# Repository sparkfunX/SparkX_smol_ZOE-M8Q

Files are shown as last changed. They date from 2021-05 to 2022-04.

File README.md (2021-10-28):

# SparkX smôl ZOE-M8Q

SparkX smôl ZOE-M8Q (SPX-18623) (https://www.sparkfun.com/products/18623)

[*SparkX smôl ZOE-M8Q (SPX-18623)*](https://www.sparkfun.com/products/18623)

The u-blox ZOE-M8Q in smôl format.

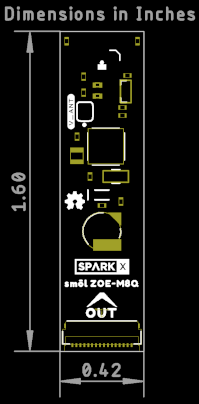
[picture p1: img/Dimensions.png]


## Repository Contents

- **/Documentation** - Datasheets etc.
- **/Hardware** - Eagle design files
- **LICENSE.md** contains the licence information

## Product Versions

- [SPX-18623](https://www.sparkfun.com/products/18623) - Original SparkX Release.

## License Information

This product is _**open source**_!

Please review the LICENSE.md file for license information.

If you have any questions or concerns on licensing, please contact technical support on our [SparkFun forums](https://forum.sparkfun.com/viewforum.php?f=123).

Distributed as-is; no warranty is given.

- Your friends at SparkFun.

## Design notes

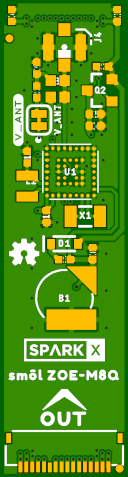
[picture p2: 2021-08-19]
img/Top.png

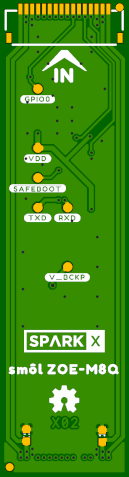
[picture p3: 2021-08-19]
img/Bottom.png

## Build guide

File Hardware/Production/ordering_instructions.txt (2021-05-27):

JLCPCB JLC7628 4-Layer 0.8mm Impedance Control
panel size, 193x137mm
PCB thickness, 0.8mm
number of layers, 4
soldermask color, Black
silkscreen color, White
oz copper, 1oz
finish, ENIG
stencils, top+bottom
pcs per panel, 48
min trace width, 0.1270mm / 0.0050in
min drill size, 0.2000mm / 0.0079in
filename to layer stackup 1/2/3/4: GTL, GL2, GL3, GBL

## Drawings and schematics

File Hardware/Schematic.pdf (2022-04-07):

# VDD GND

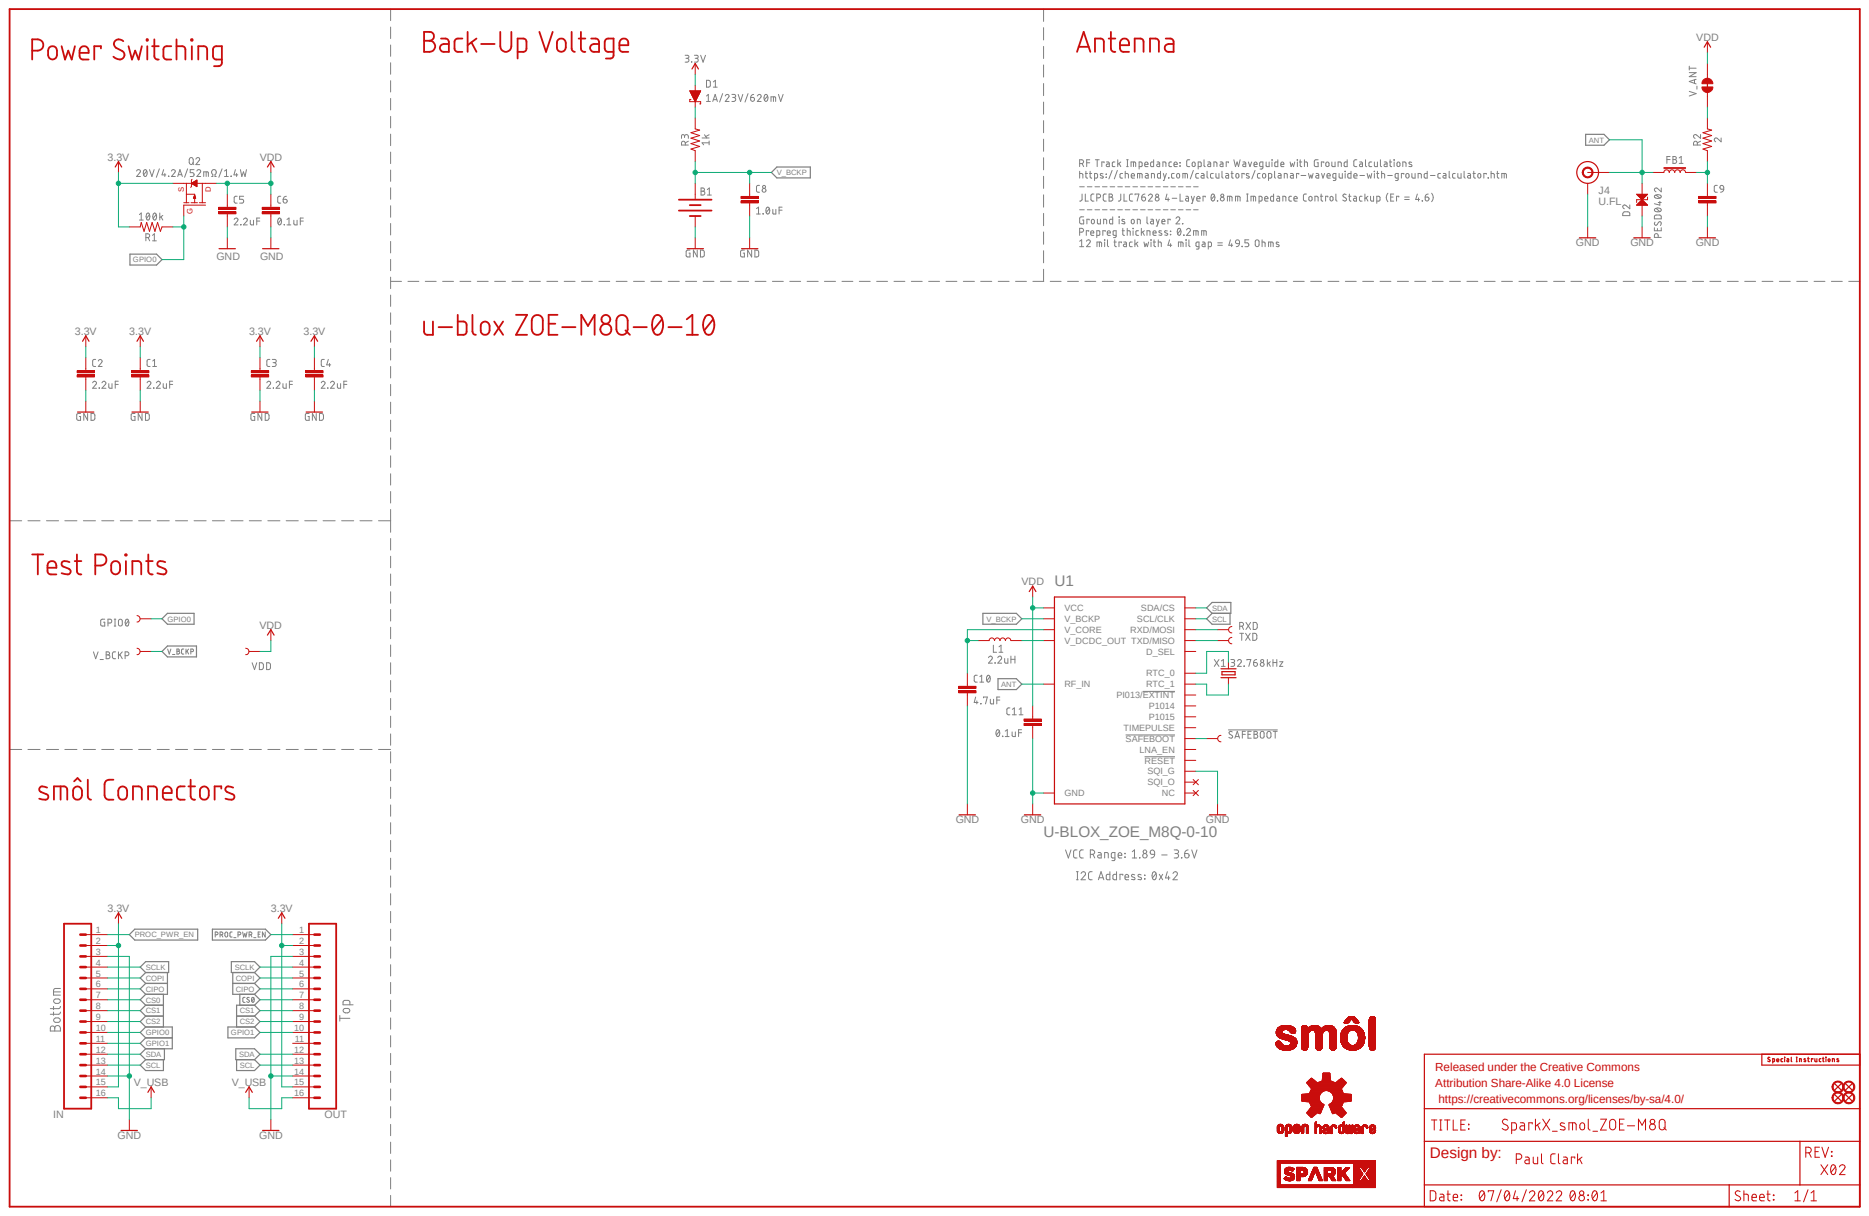
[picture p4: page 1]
VDD GND; GND; VDD; V_USB; U-BLOX_ZOE_M8Q-0-10; GND GND; 1 2 3 4 5 6 7 8 9 10 11 12 13 14 15 16 OUT; VCC GND; RTC_0 RTC_1 TIMEPULSE; SAFEBOOT LNA_EN; P1015 P1014 PI013/EXTINT RESET SQI_G; V_CORE V_DCDC_OUT; V_BCKP; SQI_O NC; SCLK; SCLK COPI; COPI CIPO; CIPO; GPIO0; GPIO0 CS1; CS2 GPIO1; GPIO1 SDA; SDA; SCL; SCL ANT; ANT; PROC_PWR_EN; Design by:

SDA/CS
SCL/CLK D_SEL RXD/MOSI TXD/MISO

Released under the Creative Commons
Attribution Share-Alike 4.0 License
https://creativecommons.org/licenses/by-sa/4.0/

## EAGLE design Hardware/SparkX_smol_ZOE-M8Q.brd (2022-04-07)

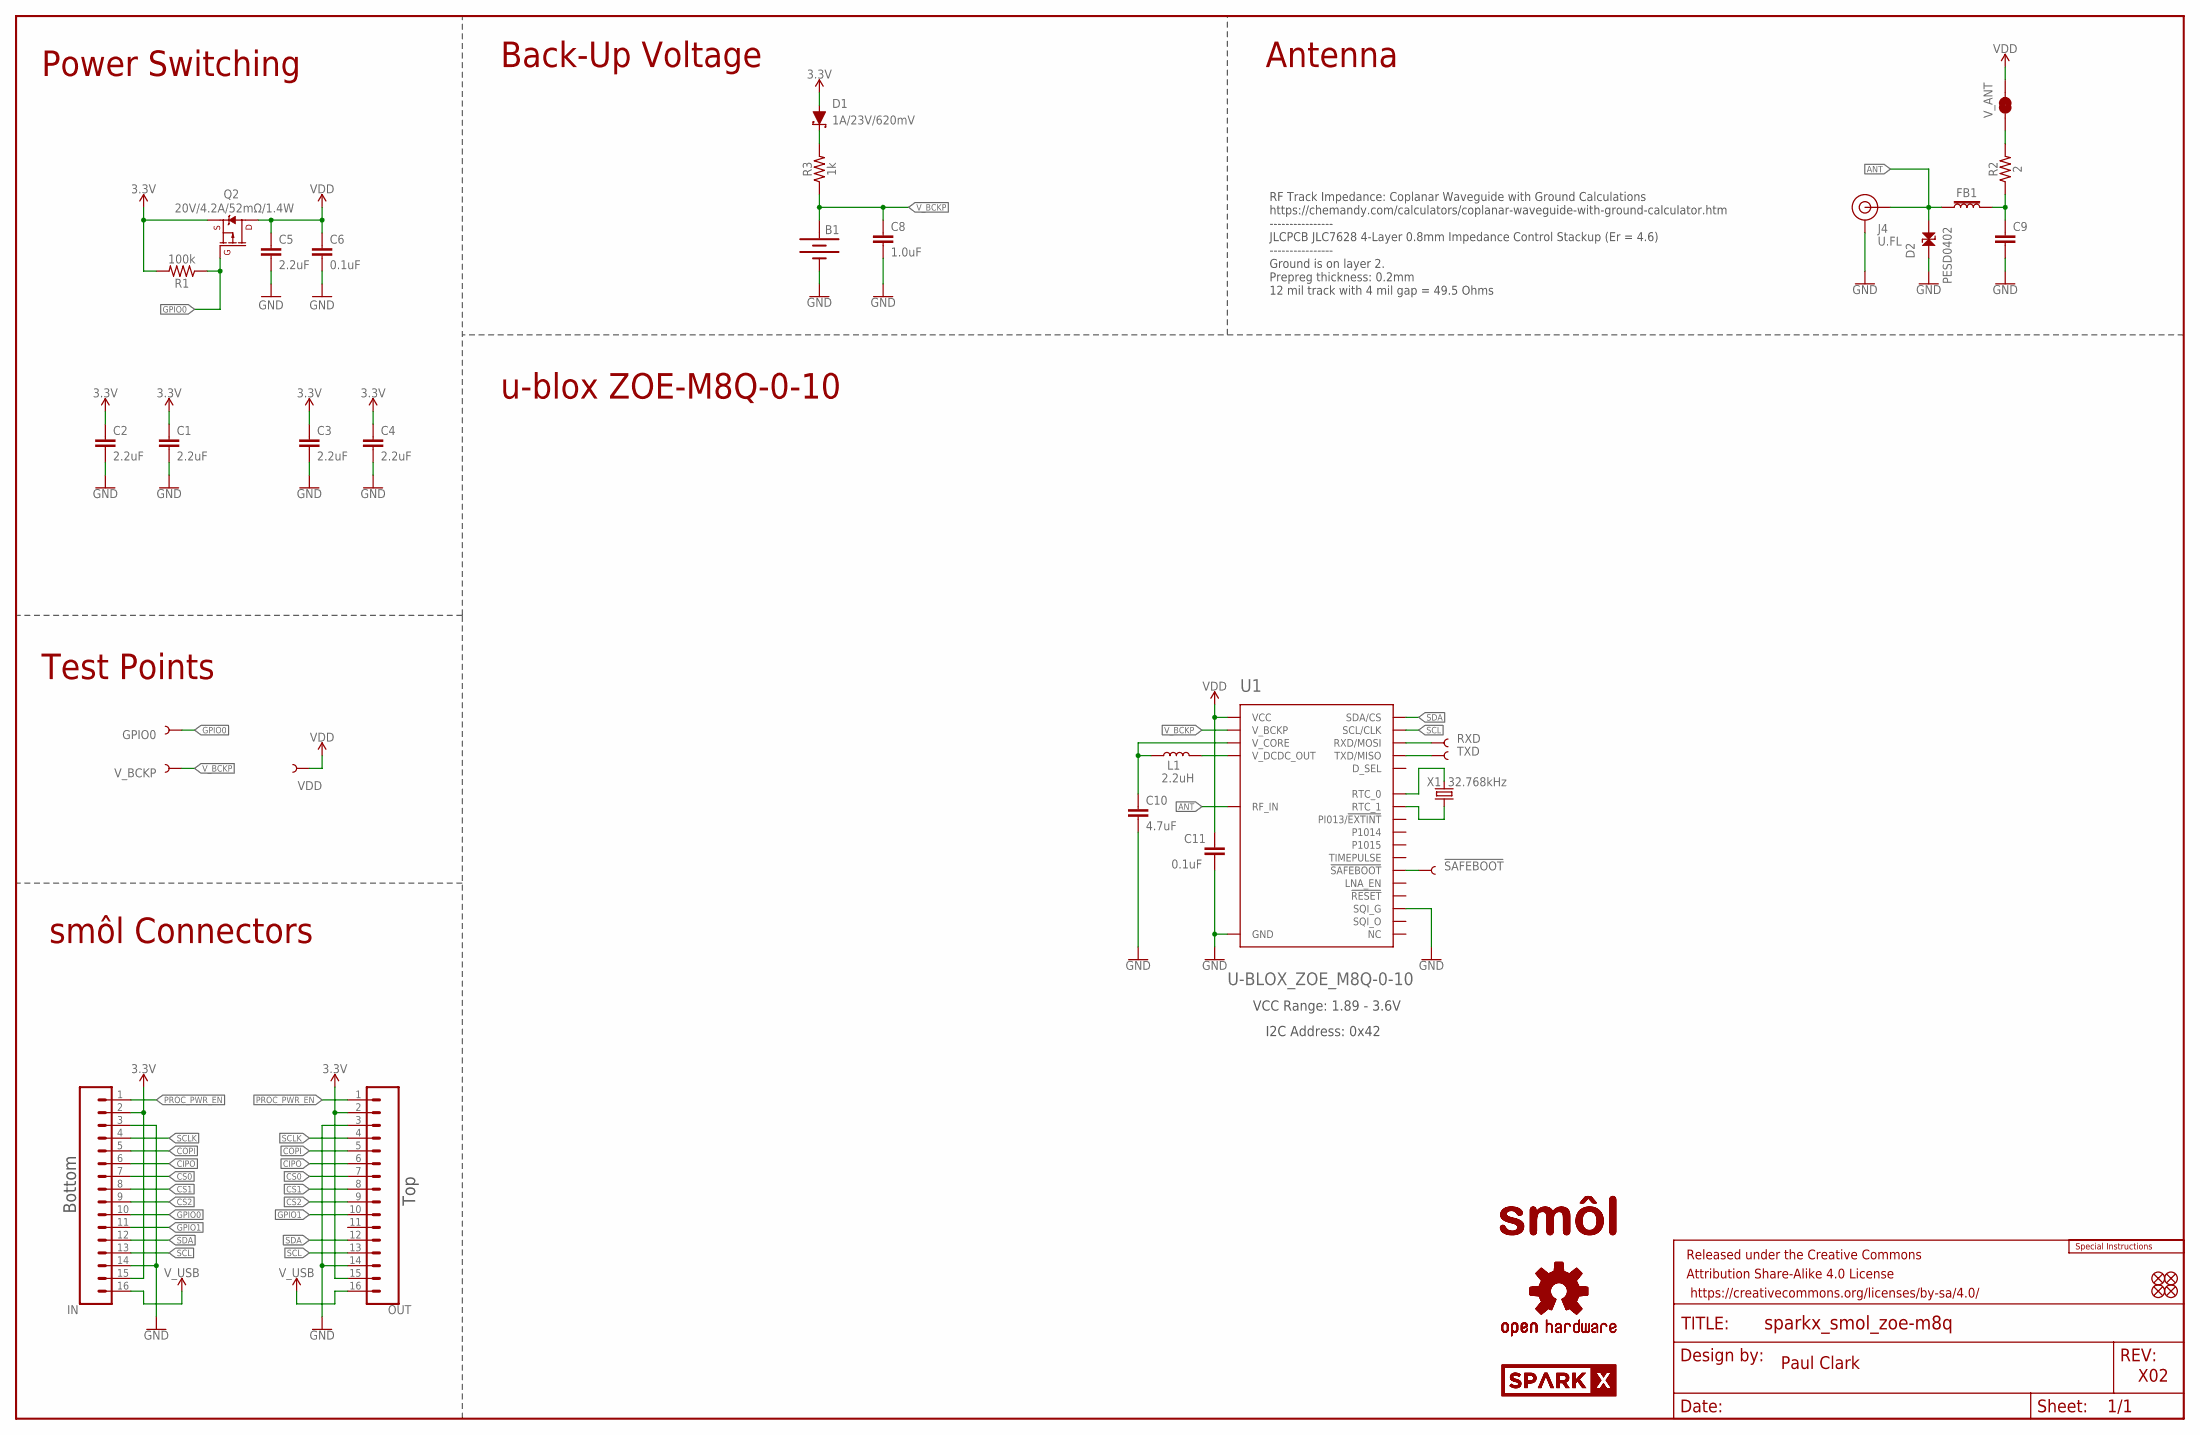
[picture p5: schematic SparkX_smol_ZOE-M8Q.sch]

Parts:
!SAFEBOOT!: TEST-POINT3; PAD.03X.03
B1: 6.8MM_COIN_CELL; ML414H_IV01E
C1, C2, C3, C4, C5: 2.2uF; 0402-TIGHT
C6, C11: 0.1uF; 0402-TIGHT
C8: 1.0uF; 0402-TIGHT
C9: 47PF-0402_TIGHT-25V-5%-X7R; 0402-TIGHT
C10: 4.7uF; 0402-TIGHT
D1: 1A/23V/620mV; SOD-323
D2: PESD0402; 0402
FB1: FERRITE_BEAD-120_OHM-0402; 0402
FD1, FD2, FD3, FD4: FIDUCIALUFIDUCIAL; FIDUCIAL-MICRO
FRAME1: FRAME-LEDGER; CREATIVE_COMMONS
GPIO0: TEST-POINT3; PAD.03X.03
IN: CONN_16FPC_16_0.5MM; FPC_16_0.5MM
J4: U.FL
L1: 2.2uH; 0806
LOGO1: SPECIAL_INSTRUCTIONS-ORDERING; ORDERING_INSTRUCTIONS
LOGO2, LOGO3: OSHW-LOGOMINI; OSHW-LOGO-MINI
OUT: CONN_16FPC_16_0.5MM; FPC_16_0.5MM
Q2: 20V/4.2A/52mΩ/1.4W; SOT23-3
R1: 100k; 0402-TIGHT
R2: 2; 0402-TIGHT
R3: 1k; 0402-TIGHT
RXD: TEST-POINT3; PAD.03X.03
TXD: TEST-POINT3; PAD.03X.03
U1: U-BLOX_ZOE_M8Q-0-10; UBLOX_ZOE_M8-0-10
U$1, U$4: SPARKX-LOGO3; SPARKX-SMALL
U$3, U$13: SMOL_LOGOSMALL; SMOL_SMALL
VDD: TEST-POINT3; PAD.03X.03
V_ANT: JUMPER-SMT_2_NC_TRACE_SILK; SMT-JUMPER_2_NC_TRACE_SILK
V_BCKP: TEST-POINT3; PAD.03X.03
X1: 32.768kHz; CRYSTAL-SMD-3.2X1.5MM

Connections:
3.3V: C1.1, C2.1, C3.1, C4.1, D1.A, IN.2, IN.15, OUT.2, OUT.15, Q2.2 (S), R1.2
!SAFEBOOT!: !SAFEBOOT!.1, U1.34 (!SAFEBOOT)
ANT: D2.2, FB1.1, J4.FEED (SIGNAL), U1.4 (RF_IN)
CIPO: IN.6, OUT.6
COPI: IN.5, OUT.5
CS0: IN.7, OUT.7
CS1: IN.8, OUT.8
CS2: IN.9, OUT.9
GND: B1.-, C1.2, C2.2, C3.2, C4.2, C5.2, C6.2, C8.2, C9.2, C10.2, C11.2, D2.1, IN.3, IN.14, J4.1 (GND), J4.2 (GND), OUT.3, OUT.14, U1.1 (GND), U1.3 (GND), U1.5 (GND), U1.7 (GND), U1.8 (GND), U1.9 (GND), U1.10 (GND), U1.11 (GND), U1.12 (GND), U1.17 (GND), U1.23 (GND), U1.29 (SQI_G), U1.31 (SQI_G), U1.37 (GND), U1.38 (GND), U1.39 (GND), U1.40 (GND), U1.41 (GND), U1.44 (GND), U1.46 (SQI_G), U1.47 (SQI_G), U1.49 (GND)
GPIO0: GPIO0.1, IN.10, Q2.1 (G), R1.1
GPIO1: IN.11, OUT.10
unnamed: R2.2, V_ANT.1
unnamed: D1.C, R3.2
unnamed: L1.2, U1.26 (V_DCDC_OUT)
unnamed: C10.1, L1.1, U1.27 (V_CORE)
unnamed: U1.18 (RTC_0), X1.P$2 (2)
unnamed: U1.19 (RTC_1), X1.P$1 (1)
unnamed: C9.1, FB1.2, R2.1
PROC_PWR_EN: IN.1, OUT.1
RXD: RXD.1, U1.22 (RXD/MOSI)
SCL: IN.13, OUT.13, U1.32 (SCL/CLK)
SCLK: IN.4, OUT.4
SDA: IN.12, OUT.12, U1.2 (SDA/CS)
TXD: TXD.1, U1.21 (TXD/MISO)
VDD: C5.1, C6.1, C11.1, Q2.3 (D), U1.24 (VCC), U1.25 (VCC), VDD.1, V_ANT.2
V_BCKP: B1.+, C8.1, R3.1, U1.16 (V_BCKP), V_BCKP.1
V_USB: IN.16, OUT.16

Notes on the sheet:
Paul Clark
X02
Test Points
RF Track Impedance: Coplanar Waveguide with Ground Calculations https://chemandy.com/calculators/coplanar-waveguide-with-ground-calculator.htm ---------------- JLCPCB JLC7628 4-Layer 0.8mm Impedance Control Stackup (Er = 4.6) ---------------- Ground is on layer 2. Prepreg thickness: 0.2mm 12 mil tr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
Power Switching
smôl Connectors
Bottom
Top
u-blox ZOE-M8Q-0-10
Back-Up Voltage
Antenna
VCC Range: 1.89 - 3.6V
I2C Address: 0x42

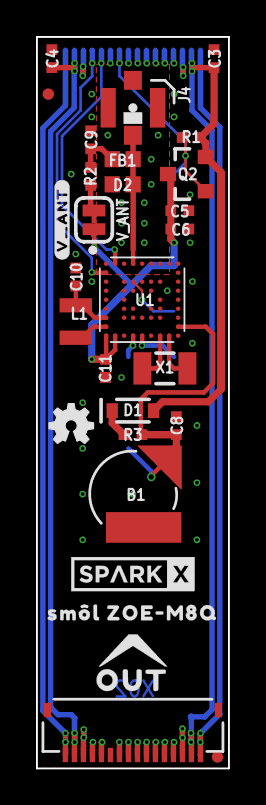
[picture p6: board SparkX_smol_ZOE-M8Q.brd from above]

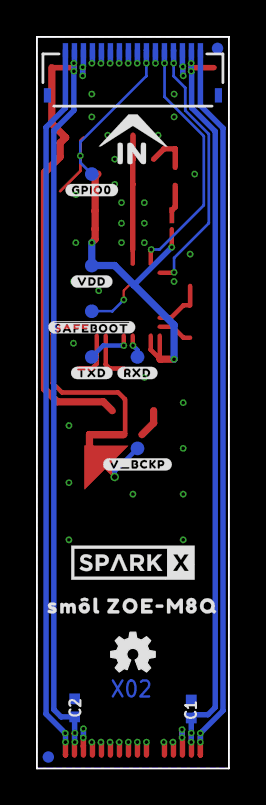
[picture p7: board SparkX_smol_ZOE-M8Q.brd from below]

Board: 4 copper layers, 10.7 x 40.6 mm, 54 parts (22 on the bottom side), 27 nets.

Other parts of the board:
U$2, U$12: SM�L_ZOE#M8Q0
U$5: #V_ANT#0
U$6: #VDD#0
U$7: ##SAFEBOOT##0
U$8: #TXD#0
U$9: #RXD#0
U$10: #GPIO0#0
U$11: #V_BCKP#0
U$14: OUT0
U$15: IN0

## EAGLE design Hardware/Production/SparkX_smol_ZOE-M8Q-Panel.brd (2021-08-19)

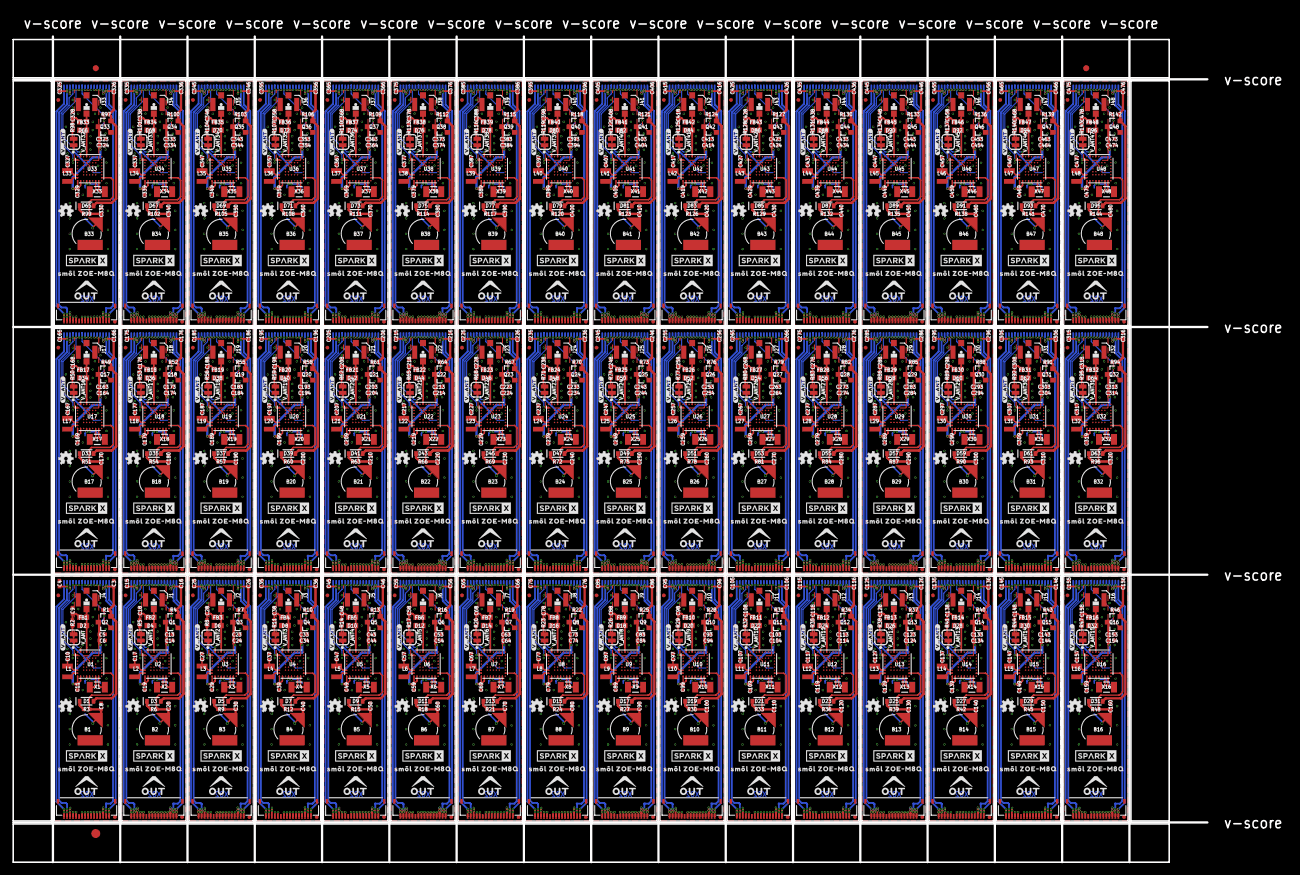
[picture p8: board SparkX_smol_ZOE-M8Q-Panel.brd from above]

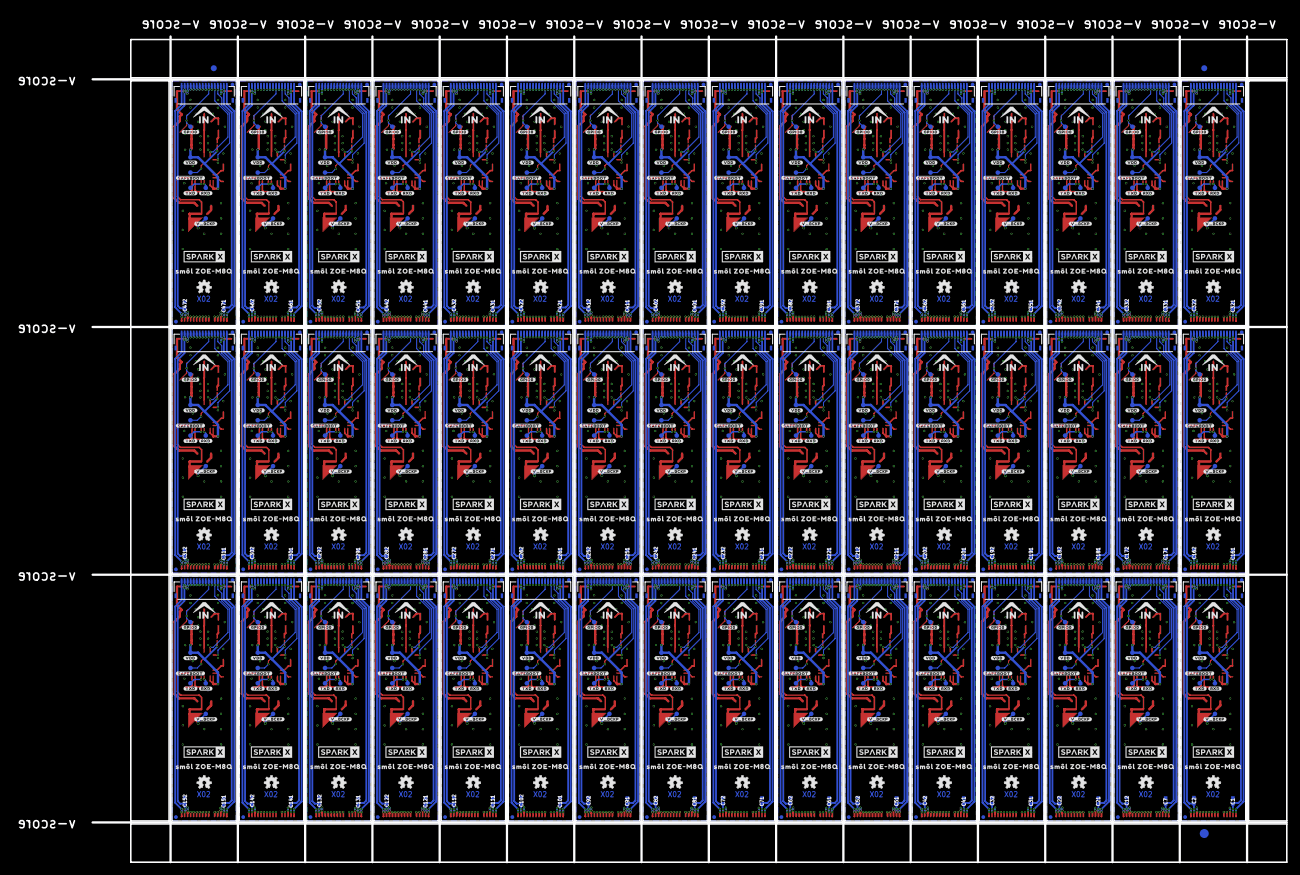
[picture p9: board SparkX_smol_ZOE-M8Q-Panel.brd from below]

Board: 4 copper layers, 198.4 x 137.2 mm, 2502 parts (1059 on the bottom side), 1296 nets.

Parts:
!SAFEBOOT!, !SAFEBOOT!1, !SAFEBOOT!2, !SAFEBOOT!3, !SAFEBOOT!4, !SAFEBOOT!5, !SAFEBOOT!6, !SAFEBOOT!7, !SAFEBOOT!8, !SAFEBOOT!9, !SAFEBOOT!10, !SAFEBOOT!11, !SAFEBOOT!12, !SAFEBOOT!13, !SAFEBOOT!14, !SAFEBOOT!15, !SAFEBOOT!16, !SAFEBOOT!17, !SAFEBOOT!18, !SAFEBOOT!19, !SAFEBOOT!20, !SAFEBOOT!21, !SAFEBOOT!22, !SAFEBOOT!23, !SAFEBOOT!24, !SAFEBOOT!25, !SAFEBOOT!26, !SAFEBOOT!27, !SAFEBOOT!28, !SAFEBOOT!29, !SAFEBOOT!30, !SAFEBOOT!31, !SAFEBOOT!32, !SAFEBOOT!33, !SAFEBOOT!34, !SAFEBOOT!35, !SAFEBOOT!36, !SAFEBOOT!37, !SAFEBOOT!38, !SAFEBOOT!39, !SAFEBOOT!40, !SAFEBOOT!41, !SAFEBOOT!42, !SAFEBOOT!43, !SAFEBOOT!44, !SAFEBOOT!45, !SAFEBOOT!46, !SAFEBOOT!47: TEST-POINT3; PAD.03X.03
B1, B2, B3, B4, B5, B6, B7, B8, B9, B10, B11, B12, B13, B14, B15, B16, B17, B18, B19, B20, B21, B22, B23, B24, B25, B26, B27, B28, B29, B30, B31, B32, B33, B34, B35, B36, B37, B38, B39, B40, B41, B42, B43, B44, B45, B46, B47, B48: 6.8MM_COIN_CELL; ML414H_IV01E
C1, C2, C3, C4, C5, C7, C12, C13, C15, C16, C21, C22, C23, C25, C26, C31, C32, C33, C35, C36, C41, C42, C43, C45, C46, C51, C52, C53, C55, C56, C61, C62, C63, C65, C66, C71, C72, C73, C75, C76, C81, C82, C83, C85, C86, C91, C92, C93, C95, C96, C101, C102, C103, C105, C106, C111, C112, C113, C115, C116, C121, C122, C123, C125, C126, C131, C132, C133, C135, C136, C141, C142, C143, C145, C146, C151, C152, C153, C155, C156, C161, C162, C163, C165, C166, C171, C172, C173, C175, C176, C181, C182, C183, C185, C186, C191, C192, C193, C195, C196, C201, C202, C203, C205, C206, C211, C212, C213, C215, C216, C221, C222, C223, C225, C226, C231, C232, C233, C235, C236, C241, C242, C243, C245, C246, C251, C252, C253, C255, C256, C261, C262, C263, C265, C266, C271, C272, C273, C275, C276, C281, C282, C283, C285, C286, C291, C292, C293, C295, C296, C301, C302, C303, C305, C306, C311, C312, C313, C315, C316, C321, C322, C323, C325, C326, C331, C332, C333, C335, C336, C341, C342, C343, C345, C346, C351, C352, C353, C355, C356, C361, C362, C363, C365, C366, C371, C372, C373, C375, C376, C381, C382, C383, C385, C386, C391, C392, C393, C395, C396, C401, C402, C403, C405, C406, C411, C412, C413, C415, C416, C421, C422, C423, C425, C426, C431, C432, C433, C435, C436, C441, C442, C443, C445, C446, C451, C452, C453, C455, C456, C461, C462, C463, C465, C466, C471, C472, C473, C475, C476: 2.2uF; 0402-TIGHT
C6, C11, C14, C19, C24, C29, C34, C39, C44, C49, C54, C59, C64, C69, C74, C79, C84, C89, C94, C99, C104, C109, C114, C119, C124, C129, C134, C139, C144, C149, C154, C159, C164, C169, C174, C179, C184, C189, C194, C199, C204, C209, C214, C219, C224, C229, C234, C239, C244, C249, C254, C259, C264, C269, C274, C279, C284, C289, C294, C299, C304, C309, C314, C319, C324, C329, C334, C339, C344, C349, C354, C359, C364, C369, C374, C379, C384, C389, C394, C399, C404, C409, C414, C419, C424, C429, C434, C439, C444, C449, C454, C459, C464, C469, C474, C479: 0.1uF; 0402-TIGHT
C8, C20, C30, C40, C50, C60, C70, C80, C90, C100, C110, C120, C130, C140, C150, C160, C170, C180, C190, C200, C210, C220, C230, C240, C250, C260, C270, C280, C290, C300, C310, C320, C330, C340, C350, C360, C370, C380, C390, C400, C410, C420, C430, C440, C450, C460, C470, C480: 1.0uF; 0402-TIGHT
C9, C18, C28, C38, C48, C58, C68, C78, C88, C98, C108, C118, C128, C138, C148, C158, C168, C178, C188, C198, C208, C218, C228, C238, C248, C258, C268, C278, C288, C298, C308, C318, C328, C338, C348, C358, C368, C378, C388, C398, C408, C418, C428, C438, C448, C458, C468, C478: 47PF-0402_TIGHT-25V-5%-X7R; 0402-TIGHT
C10, C17, C27, C37, C47, C57, C67, C77, C87, C97, C107, C117, C127, C137, C147, C157, C167, C177, C187, C197, C207, C217, C227, C237, C247, C257, C267, C277, C287, C297, C307, C317, C327, C337, C347, C357, C367, C377, C387, C397, C407, C417, C427, C437, C447, C457, C467, C477: 4.7uF; 0402-TIGHT
D1, D3, D5, D7, D9, D11, D13, D15, D17, D19, D21, D23, D25, D27, D29, D31, D33, D35, D37, D39, D41, D43, D45, D47, D49, D51, D53, D55, D57, D59, D61, D63, D65, D67, D69, D71, D73, D75, D77, D79, D81, D83, D85, D87, D89, D91, D93, D95: 1A/23V/620mV; SOD-323
D2, D4, D6, D8, D10, D12, D14, D16, D18, D20, D22, D24, D26, D28, D30, D32, D34, D36, D38, D40, D42, D44, D46, D48, D50, D52, D54, D56, D58, D60, D62, D64, D66, D68, D70, D72, D74, D76, D78, D80, D82, D84, D86, D88, D90, D92, D94, D96: PESD0402; 0402
E$1, E$2, E$3, E$4: FIDUCIAL-1X2
E$5, E$6: FIDUCIAL-1.5X3
FB1, FB2, FB3, FB4, FB5, FB6, FB7, FB8, FB9, FB10, FB11, FB12, FB13, FB14, FB15, FB16, FB17, FB18, FB19, FB20, FB21, FB22, FB23, FB24, FB25, FB26, FB27, FB28, FB29, FB30, FB31, FB32, FB33, FB34, FB35, FB36, FB37, FB38, FB39, FB40, FB41, FB42, FB43, FB44, FB45, FB46, FB47, FB48: FERRITE_BEAD-120_OHM-0402; 0402
FD1, FD2, FD3, FD4, FD5, FD6, FD7, FD8, FD9, FD10, FD11, FD12, FD13, FD14, FD15, FD16, FD17, FD18, FD19, FD20, FD21, FD22, FD23, FD24, FD25, FD26, FD27, FD28, FD29, FD30, FD31, FD32, FD33, FD34, FD35, FD36, FD37, FD38, FD39, FD40, FD41, FD42, FD43, FD44, FD45, FD46, FD47, FD48, FD49, FD50, FD51, FD52, FD53, FD54, FD55, FD56, FD57, FD58, FD59, FD60, FD61, FD62, FD63, FD64, FD65, FD66, FD67, FD68, FD69, FD70, FD71, FD72, FD73, FD74, FD75, FD76, FD77, FD78, FD79, FD80, FD81, FD82, FD83, FD84, FD85, FD86, FD87, FD88, FD89, FD90, FD91, FD92, FD93, FD94, FD95, FD96, FD97, FD98, FD99, FD100, FD101, FD102, FD103, FD104, FD105, FD106, FD107, FD108, FD109, FD110, FD111, FD112, FD113, FD114, FD115, FD116, FD117, FD118, FD119, FD120, FD121, FD122, FD123, FD124, FD125, FD126, FD127, FD128, FD129, FD130, FD131, FD132, FD133, FD134, FD135, FD136, FD137, FD138, FD139, FD140, FD141, FD142, FD143, FD144, FD145, FD146, FD147, FD148, FD149, FD150, FD151, FD152, FD153, FD154, FD155, FD156, FD157, FD158, FD159, FD160, FD161, FD162, FD163, FD164, FD165, FD166, FD167, FD168, FD169, FD170, FD171, FD172, FD173, FD174, FD175, FD176, FD177, FD178, FD179, FD180, FD181, FD182, FD183, FD184, FD185, FD186, FD187, FD188, FD189, FD190, FD191, FD192: FIDUCIALUFIDUCIAL; FIDUCIAL-MICRO
GPIO0, GPIO1, GPIO2, GPIO3, GPIO4, GPIO5, GPIO6, GPIO7, GPIO8, GPIO9, GPIO10, GPIO11, GPIO12, GPIO13, GPIO14, GPIO15, GPIO16, GPIO17, GPIO18, GPIO19, GPIO20, GPIO21, GPIO22, GPIO23, GPIO24, GPIO25, GPIO26, GPIO27, GPIO28, GPIO29, GPIO30, GPIO31, GPIO32, GPIO33, GPIO34, GPIO35, GPIO36, GPIO37, GPIO38, GPIO39, GPIO40, GPIO41, GPIO42, GPIO43, GPIO44, GPIO45, GPIO46, GPIO47: TEST-POINT3; PAD.03X.03
IN, IN1, IN2, IN3, IN4, IN5, IN6, IN7, IN8, IN9, IN10, IN11, IN12, IN13, IN14, IN15, IN16, IN17, IN18, IN19, IN20, IN21, IN22, IN23, IN24, IN25, IN26, IN27, IN28, IN29, IN30, IN31, IN32, IN33, IN34, IN35, IN36, IN37, IN38, IN39, IN40, IN41, IN42, IN43, IN44, IN45, IN46, IN47: FPC_16_0.5MM
J1, J2, J3, J4, J5, J6, J7, J8, J9, J10, J11, J12, J13, J14, J15, J16, J17, J18, J19, J20, J21, J22, J23, J24, J25, J26, J27, J28, J29, J30, J31, J32, J33, J34, J35, J36, J37, J38, J39, J40, J41, J42, J43, J44, J45, J46, J47, J48: U.FL
L1, L2, L3, L4, L5, L6, L7, L8, L9, L10, L11, L12, L13, L14, L15, L16, L17, L18, L19, L20, L21, L22, L23, L24, L25, L26, L27, L28, L29, L30, L31, L32, L33, L34, L35, L36, L37, L38, L39, L40, L41, L42, L43, L44, L45, L46, L47, L48: 2.2uH; 0806
LOGO1, LOGO2, LOGO3, LOGO4, LOGO5, LOGO6, LOGO7, LOGO8, LOGO9, LOGO10, LOGO11, LOGO12, LOGO13, LOGO14, LOGO15, LOGO16, LOGO17, LOGO18, LOGO19, LOGO20, LOGO21, LOGO22, LOGO23, LOGO24, LOGO25, LOGO26, LOGO27, LOGO28, LOGO29, LOGO30, LOGO31, LOGO32, LOGO33, LOGO34, LOGO35, LOGO36, LOGO37, LOGO38, LOGO39, LOGO40, LOGO41, LOGO42, LOGO43, LOGO44, LOGO45, LOGO46, LOGO47, LOGO48, LOGO49, LOGO50, LOGO51, LOGO52, LOGO53, LOGO54, LOGO55, LOGO56, LOGO57, LOGO58, LOGO59, LOGO60, LOGO61, LOGO62, LOGO63, LOGO64, LOGO65, LOGO66, LOGO67, LOGO68, LOGO69, LOGO70, LOGO71, LOGO72, LOGO73, LOGO74, LOGO75, LOGO76, LOGO77, LOGO78, LOGO79, LOGO80, LOGO81, LOGO82, LOGO83, LOGO84, LOGO85, LOGO86, LOGO87, LOGO88, LOGO89, LOGO90, LOGO91, LOGO92, LOGO93, LOGO94, LOGO95, LOGO96: OSHW-LOGOMINI; OSHW-LOGO-MINI
OUT, OUT1, OUT2, OUT3, OUT4, OUT5, OUT6, OUT7, OUT8, OUT9, OUT10, OUT11, OUT12, OUT13, OUT14, OUT15, OUT16, OUT17, OUT18, OUT19, OUT20, OUT21, OUT22, OUT23, OUT24, OUT25, OUT26, OUT27, OUT28, OUT29, OUT30, OUT31, OUT32, OUT33, OUT34, OUT35, OUT36, OUT37, OUT38, OUT39, OUT40, OUT41, OUT42, OUT43, OUT44, OUT45, OUT46, OUT47: FPC_16_0.5MM
Q1, Q2, Q3, Q4, Q5, Q6, Q7, Q8, Q9, Q10, Q11, Q12, Q13, Q14, Q15, Q16, Q17, Q18, Q19, Q20, Q21, Q22, Q23, Q24, Q25, Q26, Q27, Q28, Q29, Q30, Q31, Q32, Q33, Q34, Q35, Q36, Q37, Q38, Q39, Q40, Q41, Q42, Q43, Q44, Q45, Q46, Q47, Q48: 20V/4.2A/52mΩ/1.4W; SOT23-3
R1, R4, R7, R10, R13, R16, R19, R22, R25, R28, R31, R34, R37, R40, R43, R46, R49, R52, R55, R58, R61, R64, R67, R70, R73, R76, R79, R82, R85, R88, R91, R94, R97, R100, R103, R106, R109, R112, R115, R118, R121, R124, R127, R130, R133, R136, R139, R142: 100k; 0402-TIGHT
R2, R5, R8, R11, R14, R17, R20, R23, R26, R29, R32, R35, R38, R41, R44, R47, R50, R53, R56, R59, R62, R65, R68, R71, R74, R77, R80, R83, R86, R89, R92, R95, R98, R101, R104, R107, R110, R113, R116, R119, R122, R125, R128, R131, R134, R137, R140, R143: 2; 0402-TIGHT
R3, R6, R9, R12, R15, R18, R21, R24, R27, R30, R33, R36, R39, R42, R45, R48, R51, R54, R57, R60, R63, R66, R69, R72, R75, R78, R81, R84, R87, R90, R93, R96, R99, R102, R105, R108, R111, R114, R117, R120, R123, R126, R129, R132, R135, R138, R141, R144: 1k; 0402-TIGHT
RXD, RXD1, RXD2, RXD3, RXD4, RXD5, RXD6, RXD7, RXD8, RXD9, RXD10, RXD11, RXD12, RXD13, RXD14, RXD15, RXD16, RXD17, RXD18, RXD19, RXD20, RXD21, RXD22, RXD23, RXD24, RXD25, RXD26, RXD27, RXD28, RXD29, RXD30, RXD31, RXD32, RXD33, RXD34, RXD35, RXD36, RXD37, RXD38, RXD39, RXD40, RXD41, RXD42, RXD43, RXD44, RXD45, RXD46, RXD47: TEST-POINT3; PAD.03X.03
TXD, TXD1, TXD2, TXD3, TXD4, TXD5, TXD6, TXD7, TXD8, TXD9, TXD10, TXD11, TXD12, TXD13, TXD14, TXD15, TXD16, TXD17, TXD18, TXD19, TXD20, TXD21, TXD22, TXD23, TXD24, TXD25, TXD26, TXD27, TXD28, TXD29, TXD30, TXD31, TXD32, TXD33, TXD34, TXD35, TXD36, TXD37, TXD38, TXD39, TXD40, TXD41, TXD42, TXD43, TXD44, TXD45, TXD46, TXD47: TEST-POINT3; PAD.03X.03
U1, U2, U3, U4, U5, U6, U7, U8, U9, U10, U11, U12, U13, U14, U15, U16, U17, U18, U19, U20, U21, U22, U23, U24, U25, U26, U27, U28, U29, U30, U31, U32, U33, U34, U35, U36, U37, U38, U39, U40, U41, U42, U43, U44, U45, U46, U47, U48: U-BLOX_ZOE_M8Q-0-10; UBLOX_ZOE_M8-0-10
U$1, U$4, U$16, U$17, U$31, U$32, U$46, U$47, U$61, U$62, U$76, U$77, U$91, U$92, U$106, U$107, U$121, U$122, U$136, U$137, U$151, U$152, U$166, U$167, U$181, U$182, U$196, U$197, U$211, U$212, U$226, U$227, U$241, U$242, U$256, U$257, U$271, U$272, U$286, U$287, U$301, U$302, U$316, U$317, U$331, U$332, U$346, U$347, U$361, U$362, U$376, U$377, U$391, U$392, U$406, U$407, U$421, U$422, U$436, U$437, U$451, U$452, U$466, U$467, U$481, U$482, U$496, U$497, U$511, U$512, U$526, U$527, U$541, U$542, U$556, U$557, U$571, U$572, U$586, U$587, U$601, U$602, U$616, U$617, U$631, U$632, U$646, U$647, U$661, U$662, U$676, U$677, U$691, U$692, U$706, U$707: SPARKX-LOGO3; SPARKX-SMALL
U$2, U$12, U$27, U$28, U$42, U$43, U$57, U$58, U$72, U$73, U$87, U$88, U$102, U$103, U$117, U$118, U$132, U$133, U$147, U$148, U$162, U$163, U$177, U$178, U$192, U$193, U$207, U$208, U$222, U$223, U$237, U$238, U$252, U$253, U$267, U$268, U$282, U$283, U$297, U$298, U$312, U$313, U$327, U$328, U$342, U$343, U$357, U$358, U$372, U$373, U$387, U$388, U$402, U$403, U$417, U$418, U$432, U$433, U$447, U$448, U$462, U$463, U$477, U$478, U$492, U$493, U$507, U$508, U$522, U$523, U$537, U$538, U$552, U$553, U$567, U$568, U$582, U$583, U$597, U$598, U$612, U$613, U$627, U$628, U$642, U$643, U$657, U$658, U$672, U$673, U$687, U$688, U$702, U$703, U$717, U$718: SM�L_ZOE#M8Q0
U$3, U$13, U$29, U$30, U$44, U$45, U$59, U$60, U$74, U$75, U$89, U$90, U$104, U$105, U$119, U$120, U$134, U$135, U$149, U$150, U$164, U$165, U$179, U$180, U$194, U$195, U$209, U$210, U$224, U$225, U$239, U$240, U$254, U$255, U$269, U$270, U$284, U$285, U$299, U$300, U$314, U$315, U$329, U$330, U$344, U$345, U$359, U$360, U$374, U$375, U$389, U$390, U$404, U$405, U$419, U$420, U$434, U$435, U$449, U$450, U$464, U$465, U$479, U$480, U$494, U$495, U$509, U$510, U$524, U$525, U$539, U$540, U$554, U$555, U$569, U$570, U$584, U$585, U$599, U$600, U$614, U$615, U$629, U$630, U$644, U$645, U$659, U$660, U$674, U$675, U$689, U$690, U$704, U$705, U$719, U$720: SMOL_LOGOSMALL; SMOL_SMALL
U$5, U$18, U$33, U$48, U$63, U$78, U$93, U$108, U$123, U$138, U$153, U$168, U$183, U$198, U$213, U$228, U$243, U$258, U$273, U$288, U$303, U$318, U$333, U$348, U$363, U$378, U$393, U$408, U$423, U$438, U$453, U$468, U$483, U$498, U$513, U$528, U$543, U$558, U$573, U$588, U$603, U$618, U$633, U$648, U$663, U$678, U$693, U$708: #V_ANT#0
U$6, U$19, U$34, U$49, U$64, U$79, U$94, U$109, U$124, U$139, U$154, U$169, U$184, U$199, U$214, U$229, U$244, U$259, U$274, U$289, U$304, U$319, U$334, U$349, U$364, U$379, U$394, U$409, U$424, U$439, U$454, U$469, U$484, U$499, U$514, U$529, U$544, U$559, U$574, U$589, U$604, U$619, U$634, U$649, U$664, U$679, U$694, U$709: #VDD#0
U$7, U$20, U$35, U$50, U$65, U$80, U$95, U$110, U$125, U$140, U$155, U$170, U$185, U$200, U$215, U$230, U$245, U$260, U$275, U$290, U$305, U$320, U$335, U$350, U$365, U$380, U$395, U$410, U$425, U$440, U$455, U$470, U$485, U$500, U$515, U$530, U$545, U$560, U$575, U$590, U$605, U$620, U$635, U$650, U$665, U$680, U$695, U$710: ##SAFEBOOT##0
U$8, U$21, U$36, U$51, U$66, U$81, U$96, U$111, U$126, U$141, U$156, U$171, U$186, U$201, U$216, U$231, U$246, U$261, U$276, U$291, U$306, U$321, U$336, U$351, U$366, U$381, U$396, U$411, U$426, U$441, U$456, U$471, U$486, U$501, U$516, U$531, U$546, U$561, U$576, U$591, U$606, U$621, U$636, U$651, U$666, U$681, U$696, U$711: #TXD#0
U$9, U$22, U$37, U$52, U$67, U$82, U$97, U$112, U$127, U$142, U$157, U$172, U$187, U$202, U$217, U$232, U$247, U$262, U$277, U$292, U$307, U$322, U$337, U$352, U$367, U$382, U$397, U$412, U$427, U$442, U$457, U$472, U$487, U$502, U$517, U$532, U$547, U$562, U$577, U$592, U$607, U$622, U$637, U$652, U$667, U$682, U$697, U$712: #RXD#0
U$10, U$23, U$38, U$53, U$68, U$83, U$98, U$113, U$128, U$143, U$158, U$173, U$188, U$203, U$218, U$233, U$248, U$263, U$278, U$293, U$308, U$323, U$338, U$353, U$368, U$383, U$398, U$413, U$428, U$443, U$458, U$473, U$488, U$503, U$518, U$533, U$548, U$563, U$578, U$593, U$608, U$623, U$638, U$653, U$668, U$683, U$698, U$713: #GPIO0#0
U$11, U$24, U$39, U$54, U$69, U$84, U$99, U$114, U$129, U$144, U$159, U$174, U$189, U$204, U$219, U$234, U$249, U$264, U$279, U$294, U$309, U$324, U$339, U$354, U$369, U$384, U$399, U$414, U$429, U$444, U$459, U$474, U$489, U$504, U$519, U$534, U$549, U$564, U$579, U$594, U$609, U$624, U$639, U$654, U$669, U$684, U$699, U$714: #V_BCKP#0
U$14, U$25, U$40, U$55, U$70, U$85, U$100, U$115, U$130, U$145, U$160, U$175, U$190, U$205, U$220, U$235, U$250, U$265, U$280, U$295, U$310, U$325, U$340, U$355, U$370, U$385, U$400, U$415, U$430, U$445, U$460, U$475, U$490, U$505, U$520, U$535, U$550, U$565, U$580, U$595, U$610, U$625, U$640, U$655, U$670, U$685, U$700, U$715: OUT0
U$15, U$26, U$41, U$56, U$71, U$86, U$101, U$116, U$131, U$146, U$161, U$176, U$191, U$206, U$221, U$236, U$251, U$266, U$281, U$296, U$311, U$326, U$341, U$356, U$371, U$386, U$401, U$416, U$431, U$446, U$461, U$476, U$491, U$506, U$521, U$536, U$551, U$566, U$581, U$596, U$611, U$626, U$641, U$656, U$671, U$686, U$701, U$716: IN0
VDD, VDD1, VDD2, VDD3, VDD4, VDD5, VDD6, VDD7, VDD8, VDD9, VDD10, VDD11, VDD12, VDD13, VDD14, VDD15, VDD16, VDD17, VDD18, VDD19, VDD20, VDD21, VDD22, VDD23, VDD24, VDD25, VDD26, VDD27, VDD28, VDD29, VDD30, VDD31, VDD32, VDD33, VDD34, VDD35, VDD36, VDD37, VDD38, VDD39, VDD40, VDD41, VDD42, VDD43, VDD44, VDD45, VDD46, VDD47: TEST-POINT3; PAD.03X.03
V_ANT, V_ANT1, V_ANT2, V_ANT3, V_ANT4, V_ANT5, V_ANT6, V_ANT7, V_ANT8, V_ANT9, V_ANT10, V_ANT11, V_ANT12, V_ANT13, V_ANT14, V_ANT15, V_ANT16, V_ANT17, V_ANT18, V_ANT19, V_ANT20, V_ANT21, V_ANT22, V_ANT23, V_ANT24, V_ANT25, V_ANT26, V_ANT27, V_ANT28, V_ANT29, V_ANT30, V_ANT31, V_ANT32, V_ANT33, V_ANT34, V_ANT35, V_ANT36, V_ANT37, V_ANT38, V_ANT39, V_ANT40, V_ANT41, V_ANT42, V_ANT43, V_ANT44, V_ANT45, V_ANT46, V_ANT47: JUMPER-SMT_2_NC_TRACE_SILK; SMT-JUMPER_2_NC_TRACE_SILK
V_BCKP, V_BCKP1, V_BCKP2, V_BCKP3, V_BCKP4, V_BCKP5, V_BCKP6, V_BCKP7, V_BCKP8, V_BCKP9, V_BCKP10, V_BCKP11, V_BCKP12, V_BCKP13, V_BCKP14, V_BCKP15, V_BCKP16, V_BCKP17, V_BCKP18, V_BCKP19, V_BCKP20, V_BCKP21, V_BCKP22, V_BCKP23, V_BCKP24, V_BCKP25, V_BCKP26, V_BCKP27, V_BCKP28, V_BCKP29, V_BCKP30, V_BCKP31, V_BCKP32, V_BCKP33, V_BCKP34, V_BCKP35, V_BCKP36, V_BCKP37, V_BCKP38, V_BCKP39, V_BCKP40, V_BCKP41, V_BCKP42, V_BCKP43, V_BCKP44, V_BCKP45, V_BCKP46, V_BCKP47: TEST-POINT3; PAD.03X.03
X1, X2, X3, X4, X5, X6, X7, X8, X9, X10, X11, X12, X13, X14, X15, X16, X17, X18, X19, X20, X21, X22, X23, X24, X25, X26, X27, X28, X29, X30, X31, X32, X33, X34, X35, X36, X37, X38, X39, X40, X41, X42, X43, X44, X45, X46, X47, X48: 32.768kHz; CRYSTAL-SMD-3.2X1.5MM

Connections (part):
3.3V: C1.1, C2.1, C3.1, C4.1, D1.A, IN.2, IN.15, OUT.2, OUT.15, Q2.2, R1.2
3.3V1: C7.1, C12.1, C15.1, C16.1, D3.A, IN1.2, IN1.15, OUT1.2, OUT1.15, Q1.2, R4.2
3.3V2: C21.1, C22.1, C25.1, C26.1, D5.A, IN2.2, IN2.15, OUT2.2, OUT2.15, Q3.2, R7.2
3.3V3: C31.1, C32.1, C35.1, C36.1, D7.A, IN3.2, IN3.15, OUT3.2, OUT3.15, Q4.2, R10.2
3.3V4: C41.1, C42.1, C45.1, C46.1, D9.A, IN4.2, IN4.15, OUT4.2, OUT4.15, Q5.2, R13.2
3.3V5: C51.1, C52.1, C55.1, C56.1, D11.A, IN5.2, IN5.15, OUT5.2, OUT5.15, Q6.2, R16.2
3.3V6: C61.1, C62.1, C65.1, C66.1, D13.A, IN6.2, IN6.15, OUT6.2, OUT6.15, Q7.2, R19.2
3.3V7: C71.1, C72.1, C75.1, C76.1, D15.A, IN7.2, IN7.15, OUT7.2, OUT7.15, Q8.2, R22.2
3.3V8: C81.1, C82.1, C85.1, C86.1, D17.A, IN8.2, IN8.15, OUT8.2, OUT8.15, Q9.2, R25.2
3.3V9: C91.1, C92.1, C95.1, C96.1, D19.A, IN9.2, IN9.15, OUT9.2, OUT9.15, Q10.2, R28.2
3.3V10: C101.1, C102.1, C105.1, C106.1, D21.A, IN10.2, IN10.15, OUT10.2, OUT10.15, Q11.2, R31.2
3.3V11: C111.1, C112.1, C115.1, C116.1, D23.A, IN11.2, IN11.15, OUT11.2, OUT11.15, Q12.2, R34.2
3.3V12: C121.1, C122.1, C125.1, C126.1, D25.A, IN12.2, IN12.15, OUT12.2, OUT12.15, Q13.2, R37.2
3.3V13: C131.1, C132.1, C135.1, C136.1, D27.A, IN13.2, IN13.15, OUT13.2, OUT13.15, Q14.2, R40.2
3.3V14: C141.1, C142.1, C145.1, C146.1, D29.A, IN14.2, IN14.15, OUT14.2, OUT14.15, Q15.2, R43.2
3.3V15: C151.1, C152.1, C155.1, C156.1, D31.A, IN15.2, IN15.15, OUT15.2, OUT15.15, Q16.2, R46.2
3.3V16: C161.1, C162.1, C165.1, C166.1, D33.A, IN16.2, IN16.15, OUT16.2, OUT16.15, Q17.2, R49.2
3.3V17: C171.1, C172.1, C175.1, C176.1, D35.A, IN17.2, IN17.15, OUT17.2, OUT17.15, Q18.2, R52.2
3.3V18: C181.1, C182.1, C185.1, C186.1, D37.A, IN18.2, IN18.15, OUT18.2, OUT18.15, Q19.2, R55.2
3.3V19: C191.1, C192.1, C195.1, C196.1, D39.A, IN19.2, IN19.15, OUT19.2, OUT19.15, Q20.2, R58.2
3.3V20: C201.1, C202.1, C205.1, C206.1, D41.A, IN20.2, IN20.15, OUT20.2, OUT20.15, Q21.2, R61.2
3.3V21: C211.1, C212.1, C215.1, C216.1, D43.A, IN21.2, IN21.15, OUT21.2, OUT21.15, Q22.2, R64.2
3.3V22: C221.1, C222.1, C225.1, C226.1, D45.A, IN22.2, IN22.15, OUT22.2, OUT22.15, Q23.2, R67.2
3.3V23: C231.1, C232.1, C235.1, C236.1, D47.A, IN23.2, IN23.15, OUT23.2, OUT23.15, Q24.2, R70.2
3.3V24: C241.1, C242.1, C245.1, C246.1, D49.A, IN24.2, IN24.15, OUT24.2, OUT24.15, Q25.2, R73.2
3.3V25: C251.1, C252.1, C255.1, C256.1, D51.A, IN25.2, IN25.15, OUT25.2, OUT25.15, Q26.2, R76.2
3.3V26: C261.1, C262.1, C265.1, C266.1, D53.A, IN26.2, IN26.15, OUT26.2, OUT26.15, Q27.2, R79.2
3.3V27: C271.1, C272.1, C275.1, C276.1, D55.A, IN27.2, IN27.15, OUT27.2, OUT27.15, Q28.2, R82.2
3.3V28: C281.1, C282.1, C285.1, C286.1, D57.A, IN28.2, IN28.15, OUT28.2, OUT28.15, Q29.2, R85.2
3.3V29: C291.1, C292.1, C295.1, C296.1, D59.A, IN29.2, IN29.15, OUT29.2, OUT29.15, Q30.2, R88.2
3.3V30: C301.1, C302.1, C305.1, C306.1, D61.A, IN30.2, IN30.15, OUT30.2, OUT30.15, Q31.2, R91.2
3.3V31: C311.1, C312.1, C315.1, C316.1, D63.A, IN31.2, IN31.15, OUT31.2, OUT31.15, Q32.2, R94.2
3.3V32: C321.1, C322.1, C325.1, C326.1, D65.A, IN32.2, IN32.15, OUT32.2, OUT32.15, Q33.2, R97.2
3.3V33: C331.1, C332.1, C335.1, C336.1, D67.A, IN33.2, IN33.15, OUT33.2, OUT33.15, Q34.2, R100.2
3.3V34: C341.1, C342.1, C345.1, C346.1, D69.A, IN34.2, IN34.15, OUT34.2, OUT34.15, Q35.2, R103.2
3.3V35: C351.1, C352.1, C355.1, C356.1, D71.A, IN35.2, IN35.15, OUT35.2, OUT35.15, Q36.2, R106.2
3.3V36: C361.1, C362.1, C365.1, C366.1, D73.A, IN36.2, IN36.15, OUT36.2, OUT36.15, Q37.2, R109.2
3.3V37: C371.1, C372.1, C375.1, C376.1, D75.A, IN37.2, IN37.15, OUT37.2, OUT37.15, Q38.2, R112.2
3.3V38: C381.1, C382.1, C385.1, C386.1, D77.A, IN38.2, IN38.15, OUT38.2, OUT38.15, Q39.2, R115.2
3.3V39: C391.1, C392.1, C395.1, C396.1, D79.A, IN39.2, IN39.15, OUT39.2, OUT39.15, Q40.2, R118.2
3.3V40: C401.1, C402.1, C405.1, C406.1, D81.A, IN40.2, IN40.15, OUT40.2, OUT40.15, Q41.2, R121.2
3.3V41: C411.1, C412.1, C415.1, C416.1, D83.A, IN41.2, IN41.15, OUT41.2, OUT41.15, Q42.2, R124.2
3.3V42: C421.1, C422.1, C425.1, C426.1, D85.A, IN42.2, IN42.15, OUT42.2, OUT42.15, Q43.2, R127.2
3.3V43: C431.1, C432.1, C435.1, C436.1, D87.A, IN43.2, IN43.15, OUT43.2, OUT43.15, Q44.2, R130.2
3.3V44: C441.1, C442.1, C445.1, C446.1, D89.A, IN44.2, IN44.15, OUT44.2, OUT44.15, Q45.2, R133.2
3.3V45: C451.1, C452.1, C455.1, C456.1, D91.A, IN45.2, IN45.15, OUT45.2, OUT45.15, Q46.2, R136.2
3.3V46: C461.1, C462.1, C465.1, C466.1, D93.A, IN46.2, IN46.15, OUT46.2, OUT46.15, Q47.2, R139.2
3.3V47: C471.1, C472.1, C475.1, C476.1, D95.A, IN47.2, IN47.15, OUT47.2, OUT47.15, Q48.2, R142.2
!SAFEBOOT!: !SAFEBOOT!.1, U1.34
!SAFEBOOT!1: !SAFEBOOT!1.1, U2.34
!SAFEBOOT!2: !SAFEBOOT!2.1, U3.34
!SAFEBOOT!3: !SAFEBOOT!3.1, U4.34
!SAFEBOOT!4: !SAFEBOOT!4.1, U5.34
!SAFEBOOT!5: !SAFEBOOT!5.1, U6.34
!SAFEBOOT!6: !SAFEBOOT!6.1, U7.34
!SAFEBOOT!7: !SAFEBOOT!7.1, U8.34
!SAFEBOOT!8: !SAFEBOOT!8.1, U9.34
!SAFEBOOT!9: !SAFEBOOT!9.1, U10.34
!SAFEBOOT!10: !SAFEBOOT!10.1, U11.34
!SAFEBOOT!11: !SAFEBOOT!11.1, U12.34
!SAFEBOOT!12: !SAFEBOOT!12.1, U13.34
!SAFEBOOT!13: !SAFEBOOT!13.1, U14.34
!SAFEBOOT!14: !SAFEBOOT!14.1, U15.34
!SAFEBOOT!15: !SAFEBOOT!15.1, U16.34
!SAFEBOOT!16: !SAFEBOOT!16.1, U17.34
!SAFEBOOT!17: !SAFEBOOT!17.1, U18.34
!SAFEBOOT!18: !SAFEBOOT!18.1, U19.34
!SAFEBOOT!19: !SAFEBOOT!19.1, U20.34
!SAFEBOOT!20: !SAFEBOOT!20.1, U21.34
!SAFEBOOT!21: !SAFEBOOT!21.1, U22.34
!SAFEBOOT!22: !SAFEBOOT!22.1, U23.34
!SAFEBOOT!23: !SAFEBOOT!23.1, U24.34
!SAFEBOOT!24: !SAFEBOOT!24.1, U25.34
!SAFEBOOT!25: !SAFEBOOT!25.1, U26.34
!SAFEBOOT!26: !SAFEBOOT!26.1, U27.34
!SAFEBOOT!27: !SAFEBOOT!27.1, U28.34
!SAFEBOOT!28: !SAFEBOOT!28.1, U29.34
!SAFEBOOT!29: !SAFEBOOT!29.1, U30.34
!SAFEBOOT!30: !SAFEBOOT!30.1, U31.34
!SAFEBOOT!31: !SAFEBOOT!31.1, U32.34
!SAFEBOOT!32: !SAFEBOOT!32.1, U33.34
!SAFEBOOT!33: !SAFEBOOT!33.1, U34.34
!SAFEBOOT!34: !SAFEBOOT!34.1, U35.34
!SAFEBOOT!35: !SAFEBOOT!35.1, U36.34
!SAFEBOOT!36: !SAFEBOOT!36.1, U37.34
!SAFEBOOT!37: !SAFEBOOT!37.1, U38.34
!SAFEBOOT!38: !SAFEBOOT!38.1, U39.34
!SAFEBOOT!39: !SAFEBOOT!39.1, U40.34
!SAFEBOOT!40: !SAFEBOOT!40.1, U41.34
!SAFEBOOT!41: !SAFEBOOT!41.1, U42.34
!SAFEBOOT!42: !SAFEBOOT!42.1, U43.34
!SAFEBOOT!43: !SAFEBOOT!43.1, U44.34
!SAFEBOOT!44: !SAFEBOOT!44.1, U45.34
!SAFEBOOT!45: !SAFEBOOT!45.1, U46.34
!SAFEBOOT!46: !SAFEBOOT!46.1, U47.34
!SAFEBOOT!47: !SAFEBOOT!47.1, U48.34
ANT: D2.2, FB1.1, J4.FEED, U1.4
ANT1: D4.2, FB2.1, J1.FEED, U2.4
ANT2: D6.2, FB3.1, J2.FEED, U3.4
ANT3: D8.2, FB4.1, J3.FEED, U4.4
ANT4: D10.2, FB5.1, J5.FEED, U5.4
ANT5: D12.2, FB6.1, J6.FEED, U6.4
ANT6: D14.2, FB7.1, J7.FEED, U7.4
ANT7: D16.2, FB8.1, J8.FEED, U8.4
ANT8: D18.2, FB9.1, J9.FEED, U9.4
ANT9: D20.2, FB10.1, J10.FEED, U10.4
ANT10: D22.2, FB11.1, J11.FEED, U11.4
ANT11: D24.2, FB12.1, J12.FEED, U12.4
ANT12: D26.2, FB13.1, J13.FEED, U13.4
ANT13: D28.2, FB14.1, J14.FEED, U14.4
ANT14: D30.2, FB15.1, J15.FEED, U15.4
ANT15: D32.2, FB16.1, J16.FEED, U16.4
ANT16: D34.2, FB17.1, J17.FEED, U17.4
ANT17: D36.2, FB18.1, J18.FEED, U18.4
ANT18: D38.2, FB19.1, J19.FEED, U19.4
ANT19: D40.2, FB20.1, J20.FEED, U20.4
ANT20: D42.2, FB21.1, J21.FEED, U21.4
ANT21: D44.2, FB22.1, J22.FEED, U22.4
ANT22: D46.2, FB23.1, J23.FEED, U23.4
ANT23: D48.2, FB24.1, J24.FEED, U24.4
ANT24: D50.2, FB25.1, J25.FEED, U25.4
ANT25: D52.2, FB26.1, J26.FEED, U26.4
ANT26: D54.2, FB27.1, J27.FEED, U27.4
ANT27: D56.2, FB28.1, J28.FEED, U28.4
ANT28: D58.2, FB29.1, J29.FEED, U29.4
ANT29: D60.2, FB30.1, J30.FEED, U30.4
ANT30: D62.2, FB31.1, J31.FEED, U31.4
ANT31: D64.2, FB32.1, J32.FEED, U32.4
ANT32: D66.2, FB33.1, J33.FEED, U33.4
ANT33: D68.2, FB34.1, J34.FEED, U34.4
ANT34: D70.2, FB35.1, J35.FEED, U35.4
ANT35: D72.2, FB36.1, J36.FEED, U36.4
ANT36: D74.2, FB37.1, J37.FEED, U37.4
ANT37: D76.2, FB38.1, J38.FEED, U38.4
ANT38: D78.2, FB39.1, J39.FEED, U39.4
ANT39: D80.2, FB40.1, J40.FEED, U40.4
ANT40: D82.2, FB41.1, J41.FEED, U41.4
ANT41: D84.2, FB42.1, J42.FEED, U42.4
ANT42: D86.2, FB43.1, J43.FEED, U43.4
ANT43: D88.2, FB44.1, J44.FEED, U44.4
ANT44: D90.2, FB45.1, J45.FEED, U45.4
ANT45: D92.2, FB46.1, J46.FEED, U46.4
ANT46: D94.2, FB47.1, J47.FEED, U47.4
ANT47: D96.2, FB48.1, J48.FEED, U48.4
CIPO: IN.6, OUT.6
CIPO1: IN1.6, OUT1.6
CIPO2: IN2.6, OUT2.6
CIPO3: IN3.6, OUT3.6
CIPO4: IN4.6, OUT4.6
CIPO5: IN5.6, OUT5.6
CIPO6: IN6.6, OUT6.6
CIPO7: IN7.6, OUT7.6
CIPO8: IN8.6, OUT8.6
CIPO9: IN9.6, OUT9.6
CIPO10: IN10.6, OUT10.6
CIPO11: IN11.6, OUT11.6
CIPO12: IN12.6, OUT12.6
CIPO13: IN13.6, OUT13.6
CIPO14: IN14.6, OUT14.6
CIPO15: IN15.6, OUT15.6
CIPO16: IN16.6, OUT16.6
CIPO17: IN17.6, OUT17.6
CIPO18: IN18.6, OUT18.6
CIPO19: IN19.6, OUT19.6
CIPO20: IN20.6, OUT20.6
CIPO21: IN21.6, OUT21.6
CIPO22: IN22.6, OUT22.6
CIPO23: IN23.6, OUT23.6
CIPO24: IN24.6, OUT24.6
CIPO25: IN25.6, OUT25.6
CIPO26: IN26.6, OUT26.6
CIPO27: IN27.6, OUT27.6
CIPO28: IN28.6, OUT28.6
CIPO29: IN29.6, OUT29.6
CIPO30: IN30.6, OUT30.6
CIPO31: IN31.6, OUT31.6
CIPO32: IN32.6, OUT32.6
CIPO33: IN33.6, OUT33.6
CIPO34: IN34.6, OUT34.6
CIPO35: IN35.6, OUT35.6
CIPO36: IN36.6, OUT36.6
CIPO37: IN37.6, OUT37.6
CIPO38: IN38.6, OUT38.6
CIPO39: IN39.6, OUT39.6
CIPO40: IN40.6, OUT40.6
CIPO41: IN41.6, OUT41.6
CIPO42: IN42.6, OUT42.6
CIPO43: IN43.6, OUT43.6
CIPO44: IN44.6, OUT44.6
CIPO45: IN45.6, OUT45.6
CIPO46: IN46.6, OUT46.6
CIPO47: IN47.6, OUT47.6
COPI: IN.5, OUT.5
COPI1: IN1.5, OUT1.5
COPI2: IN2.5, OUT2.5
COPI3: IN3.5, OUT3.5
COPI4: IN4.5, OUT4.5
COPI5: IN5.5, OUT5.5
COPI6: IN6.5, OUT6.5
COPI7: IN7.5, OUT7.5
COPI8: IN8.5, OUT8.5
COPI9: IN9.5, OUT9.5
COPI10: IN10.5, OUT10.5
COPI11: IN11.5, OUT11.5
COPI12: IN12.5, OUT12.5
COPI13: IN13.5, OUT13.5
COPI14: IN14.5, OUT14.5
COPI15: IN15.5, OUT15.5
COPI16: IN16.5, OUT16.5
COPI17: IN17.5, OUT17.5
COPI18: IN18.5, OUT18.5
COPI19: IN19.5, OUT19.5
COPI20: IN20.5, OUT20.5
COPI21: IN21.5, OUT21.5
COPI22: IN22.5, OUT22.5
COPI23: IN23.5, OUT23.5
COPI24: IN24.5, OUT24.5
COPI25: IN25.5, OUT25.5
COPI26: IN26.5, OUT26.5
COPI27: IN27.5, OUT27.5
COPI28: IN28.5, OUT28.5
COPI29: IN29.5, OUT29.5
COPI30: IN30.5, OUT30.5
COPI31: IN31.5, OUT31.5
COPI32: IN32.5, OUT32.5
COPI33: IN33.5, OUT33.5
COPI34: IN34.5, OUT34.5
COPI35: IN35.5, OUT35.5
COPI36: IN36.5, OUT36.5
COPI37: IN37.5, OUT37.5
COPI38: IN38.5, OUT38.5
COPI39: IN39.5, OUT39.5
COPI40: IN40.5, OUT40.5
COPI41: IN41.5, OUT41.5
COPI42: IN42.5, OUT42.5
COPI43: IN43.5, OUT43.5
COPI44: IN44.5, OUT44.5
COPI45: IN45.5, OUT45.5
COPI46: IN46.5, OUT46.5
COPI47: IN47.5, OUT47.5
CS0: IN.7, OUT.7
CS1: IN.8, OUT.8
CS2: IN.9, OUT.9
CS3: IN1.7, OUT1.7
CS4: IN1.8, OUT1.8
CS5: IN1.9, OUT1.9
CS6: IN2.7, OUT2.7
CS7: IN2.8, OUT2.8
CS8: IN2.9, OUT2.9
CS9: IN3.7, OUT3.7
CS10: IN3.8, OUT3.8
CS11: IN3.9, OUT3.9
CS12: IN4.7, OUT4.7
CS13: IN4.8, OUT4.8
CS14: IN4.9, OUT4.9
CS15: IN5.7, OUT5.7
CS16: IN5.8, OUT5.8
CS17: IN5.9, OUT5.9
CS18: IN6.7, OUT6.7
CS19: IN6.8, OUT6.8
CS20: IN6.9, OUT6.9
CS21: IN7.7, OUT7.7
CS22: IN7.8, OUT7.8
CS23: IN7.9, OUT7.9
CS24: IN8.7, OUT8.7
CS25: IN8.8, OUT8.8
CS26: IN8.9, OUT8.9
CS27: IN9.7, OUT9.7
CS28: IN9.8, OUT9.8
CS29: IN9.9, OUT9.9
CS30: IN10.7, OUT10.7
CS31: IN10.8, OUT10.8
CS32: IN10.9, OUT10.9
CS33: IN11.7, OUT11.7
CS34: IN11.8, OUT11.8
CS35: IN11.9, OUT11.9
CS36: IN12.7, OUT12.7
CS37: IN12.8, OUT12.8
CS38: IN12.9, OUT12.9
CS39: IN13.7, OUT13.7
CS40: IN13.8, OUT13.8
CS41: IN13.9, OUT13.9
CS42: IN14.7, OUT14.7
CS43: IN14.8, OUT14.8
CS44: IN14.9, OUT14.9
CS45: IN15.7, OUT15.7
CS46: IN15.8, OUT15.8
CS47: IN15.9, OUT15.9
CS48: IN16.7, OUT16.7
CS49: IN16.8, OUT16.8
CS50: IN16.9, OUT16.9
CS51: IN17.7, OUT17.7
CS52: IN17.8, OUT17.8
CS53: IN17.9, OUT17.9
CS54: IN18.7, OUT18.7
CS55: IN18.8, OUT18.8
CS56: IN18.9, OUT18.9
CS57: IN19.7, OUT19.7
CS58: IN19.8, OUT19.8
CS59: IN19.9, OUT19.9
CS60: IN20.7, OUT20.7
CS61: IN20.8, OUT20.8
CS62: IN20.9, OUT20.9
CS63: IN21.7, OUT21.7
CS64: IN21.8, OUT21.8
CS65: IN21.9, OUT21.9
CS66: IN22.7, OUT22.7
CS67: IN22.8, OUT22.8
CS68: IN22.9, OUT22.9
CS69: IN23.7, OUT23.7
CS70: IN23.8, OUT23.8
CS71: IN23.9, OUT23.9
CS72: IN24.7, OUT24.7
CS73: IN24.8, OUT24.8
CS74: IN24.9, OUT24.9
CS75: IN25.7, OUT25.7
CS76: IN25.8, OUT25.8
CS77: IN25.9, OUT25.9
CS78: IN26.7, OUT26.7
CS79: IN26.8, OUT26.8
CS80: IN26.9, OUT26.9
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

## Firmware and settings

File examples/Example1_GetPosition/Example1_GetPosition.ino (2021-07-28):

/*!
 * @file Example1_GetPosition.ino
 * 
 * @mainpage SparkFun smôl ZOE-M8Q
 * 
 * @section intro_sec Examples
 * 
 * This example shows how to read the the position from the smôl ZOE-M8Q using
 * the SparkFun GNSS Library.
 * 
 * Want to support open source hardware? Buy a board from SparkFun!
 * SparkX smôl ZOE-M8Q (SPX-18358): https://www.sparkfun.com/products/18358
 * SparkX smôl ESP32 (SPX-18362): https://www.sparkfun.com/products/18362
 * 
 * @section author Author
 * 
 * This library was written by:
 * Paul Clark
 * July 28th 2021
 * 
 * @section license License
 * 
 * MIT: please see LICENSE.md for the full license information
 * 
 */

#include <Wire.h> //Needed for I2C to GNSS

#include <SparkFun_u-blox_GNSS_Arduino_Library.h> //http://librarymanager/All#SparkFun_u-blox_GNSS
SFE_UBLOX_GNSS myGNSS;

void setup()
{
  delay(1000);
  
  Serial.begin(115200);
  Serial.println("SparkFun u-blox example for the smôl ZOE-M8Q");

  // GNSS power is disabled by default on the smôl ZOE-M8.
  // We need to pull GPIO0 low to enable the power.
  // On the smôl ESP32, GPIO0 is connected to digital pin 27.
  // If you have an intermediate smôl board between the ESP32 and the ZOE-M8Q
  //  and that board also uses GPIO0, then the power enable will be connected
  //  to GPIO1 instead which is digital pin 26 on the smôl ESP32.
  pinMode(27, OUTPUT);
  digitalWrite(27, LOW); // Pull GPIO0 (digital pin 27) low to enable power for the ZOE-M8Q
  
  delay(1000); // Give the ZOE-M8Q some time to power up

  Wire.begin();

  //myGNSS.enableDebugging(); //Uncomment this line to enable helpful debug messages on Serial

  if (myGNSS.begin() == false) //Connect to the u-blox module using Wire port
  {
    Serial.println(F("u-blox GNSS not detected at default I2C address. Please check wiring. Freezing."));
    while (1);
  }

  myGNSS.setI2COutput(COM_TYPE_UBX); //Set the I2C port to output UBX only (turn off NMEA noise)
  myGNSS.saveConfigSelective(VAL_CFG_SUBSEC_IOPORT); //Save (only) the communications port settings to flash and BBR
}

void loop()
{
  //The module only responds when a new position is available
    
  Serial.print(myGNSS.getYear());
  Serial.print("/");
  Serial.print(myGNSS.getMonth());
  Serial.print("/");
  Serial.print(myGNSS.getDay());
  Serial.print(" ");
  Serial.print(myGNSS.getHour());
  Serial.print(":");
  Serial.print(myGNSS.getMinute());
  Serial.print(":");
  Serial.print(myGNSS.getSecond());

  Serial.print(F(" Lat: "));
  Serial.print(myGNSS.getLatitude());

  Serial.print(F(" Long: "));
  Serial.print(myGNSS.getLongitude());
  Serial.print(F(" (degrees * 10^-7)"));

  Serial.print(F(" Alt: "));
  Serial.print(myGNSS.getAltitudeMSL());
  Serial.print(F(" (mm)"));

  Serial.print(F(" SIV: "));
  Serial.print(myGNSS.getSIV());

  Serial.println();
}

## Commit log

2021-05-04 Review updates
    [SparkX_EZ_ZOE-M8Q.brd, SparkX_EZ_ZOE-M8Q.sch]
2021-05-04 Adding production panel
    [SparkX_EZ_ZOE-M8Q-Panel.GBL, SparkX_EZ_ZOE-M8Q-Panel.GBO, SparkX_EZ_ZOE-M8Q-Panel.GBP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]
2021-05-27 Gapless production panel
    [SparkX_EZ_ZOE-M8Q-Panel.brd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]
2021-06-09 Update 16-way FPC Connector
    [SparkX_EZ_ZOE-M8Q.brd, SparkX_EZ_ZOE-M8Q.sch]
2021-07-30 Change R2 to RES-15724
    [SparkX_EZ_ZOE-M8Q-Panel.brd, SparkX_EZ_ZOE-M8Q.brd, SparkX_EZ_ZOE-M8Q.sch]
2021-08-19 Add smôl branding
    [SparkX_EZ_ZOE-M8Q-Panel.brd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]
2021-08-20 Change EZ to smôl on schematic
    [SparkX_smol_ZOE-M8Q.sch]
2022-04-07 Update schematic
    [SparkX_smol_ZOE-M8Q.brd, SparkX_smol_ZOE-M8Q.sch]

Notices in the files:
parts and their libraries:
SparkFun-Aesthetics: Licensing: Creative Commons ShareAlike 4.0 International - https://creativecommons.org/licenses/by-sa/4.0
